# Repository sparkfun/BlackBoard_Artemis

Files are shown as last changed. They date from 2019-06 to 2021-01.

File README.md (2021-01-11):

**NOTE:** *This product has been retired from our catalog. There is an updated RedBoard version available: [DEV-15444](https://www.sparkfun.com/products/15444). If you are looking for more up-to-date info, please check out some of these resources to see how other users are still hacking and improving on this product version.*

* *[SparkFun Artemis Forum](https://forum.sparkfun.com/viewforum.php?f=167)*
* *[Comments Here on GitHub](https://github.com/sparkfun/BlackBoard_Artemis/issues)*

SparkFun BlackBoard Artemis
============================

[SparkFun BlackBoard Artemis  
*SparkFun BlackBoard (SPX-15332)*](https://www.sparkfun.com/products/15332)

Think of the BlackBoard Artemis as just another Arduino... That has BLE. And one meg of flash. And runs at less than 1mA. Oh, and it can run TensorFlow models. Ya, that too. The BlackBoard Artemis takes the incredibly powerful Artemis module from SparkFun and wraps it up in an easy to use and familiar Uno footprint. We've written an Arduino core from scratch to make programming the Artemis as familiar as `Serial.begin(9600)`. Time-to-first-blink is less than five minutes.

The BlackBoard Artemis has the improved power conditioning and USB to serial that we've refined over the years on our BlackBoard line of products. A modern USB-C connector makes programming easy. A Qwiic connector makes I<sup>2</sup>C easy. The BlackBoard Artemis is fully compatible with SparkFun's Arduino core and can be programmed easily under the Arduino IDE. We've exposed the JTAG connector for more advanced users who prefer to use the power and speed of professional tools. We've added a digital MEMS microphone for folks wanting to experiment with always-on voice commands with TensorFlow and machine learning. We've even added a convenient jumper to measure current consumption for low power testing.

With 1M flash and 384k RAM you'll have plenty of room for your sketches. The Artemis module runs at 48MHz with a 96MHz turbo mode available and with Bluetooth to boot!

The SparkFun BlackBoard Artemis is a great platform to 'kick the tires' of this amazing module. If you're interesting in testing out the full capabilities of the SparkFun Artemis module or if you're looking for more compact solution, be sure to checkout our ATP and Nano versions of the Artemis line.

**Note:** We are actively working on getting FCC and compliance certifications for the SparkFun Artemis Module. Once our certifications are complete we will be moving the BlackBoard to a RedBoard format with the FCC Certified version of the Artemis on board. *Please be aware* that this could happen as soon as a few weeks to a month so this BlackBoard version is for those of you who can't wait and want to start using the SparkFun Artemis as soon as possible!

Repository Contents
-------------------
* **/Hardware** - Eagle design files (.brd, .sch)

Documentation
-------------------
* **[Hookup Guide for the BlackBoard Artemis](https://learn.sparkfun.com/tutorials/hookup-guide-for-the-blackboard-artemis)**
* **[Designing with the SparkFun Artemis](https://learn.sparkfun.com/tutorials/designing-with-the-sparkfun-artemis)** - Layout and design considerations when using the Artemis module.
* **[Artemis Development with Arduino](https://learn.sparkfun.com/tutorials/artemis-development-with-arduino)** - Introduction to the Arduino core for the Artemis Module.
* **[Ambiq Apollo3 SDK SetUp](https://learn.sparkfun.com/tutorials/using-sparkfun-edge-board-with-ambiq-apollo3-sdk)** - Getting set up with the Apollo3 Software Development Kit.
* **[CH340E USB to serial IC Drivers](https://www.sparkfun.com/ch340)**
* **[SparkFun Fritzing repo](https://github.com/sparkfun/Fritzing_Parts)** - Fritzing diagrams for SparkFun products.
License Information
-------------------

This product is _**open source**_! 

Please review the LICENSE.md file for license information. 

If you have any questions or concerns on licensing, please contact techsupport@sparkfun.com.

Please use, reuse, and modify these files as you see fit. Please maintain attribution to SparkFun Electronics and release any derivative under the same license.

Distributed as-is; no warranty is given.

- Your friends at SparkFun.

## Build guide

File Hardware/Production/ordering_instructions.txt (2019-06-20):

panel size, 160x121mm
PCB thickness, 1.6mm
number of layers, 2
soldermask color, Red
silkscreen color, White
oz copper, 1oz
finish, HASL lead free
stencils, top+bottom
pcs per panel, 4
min trace width, 0.177800mm / 0.007000in
min drill size, 0.304800mm / 0.012000in

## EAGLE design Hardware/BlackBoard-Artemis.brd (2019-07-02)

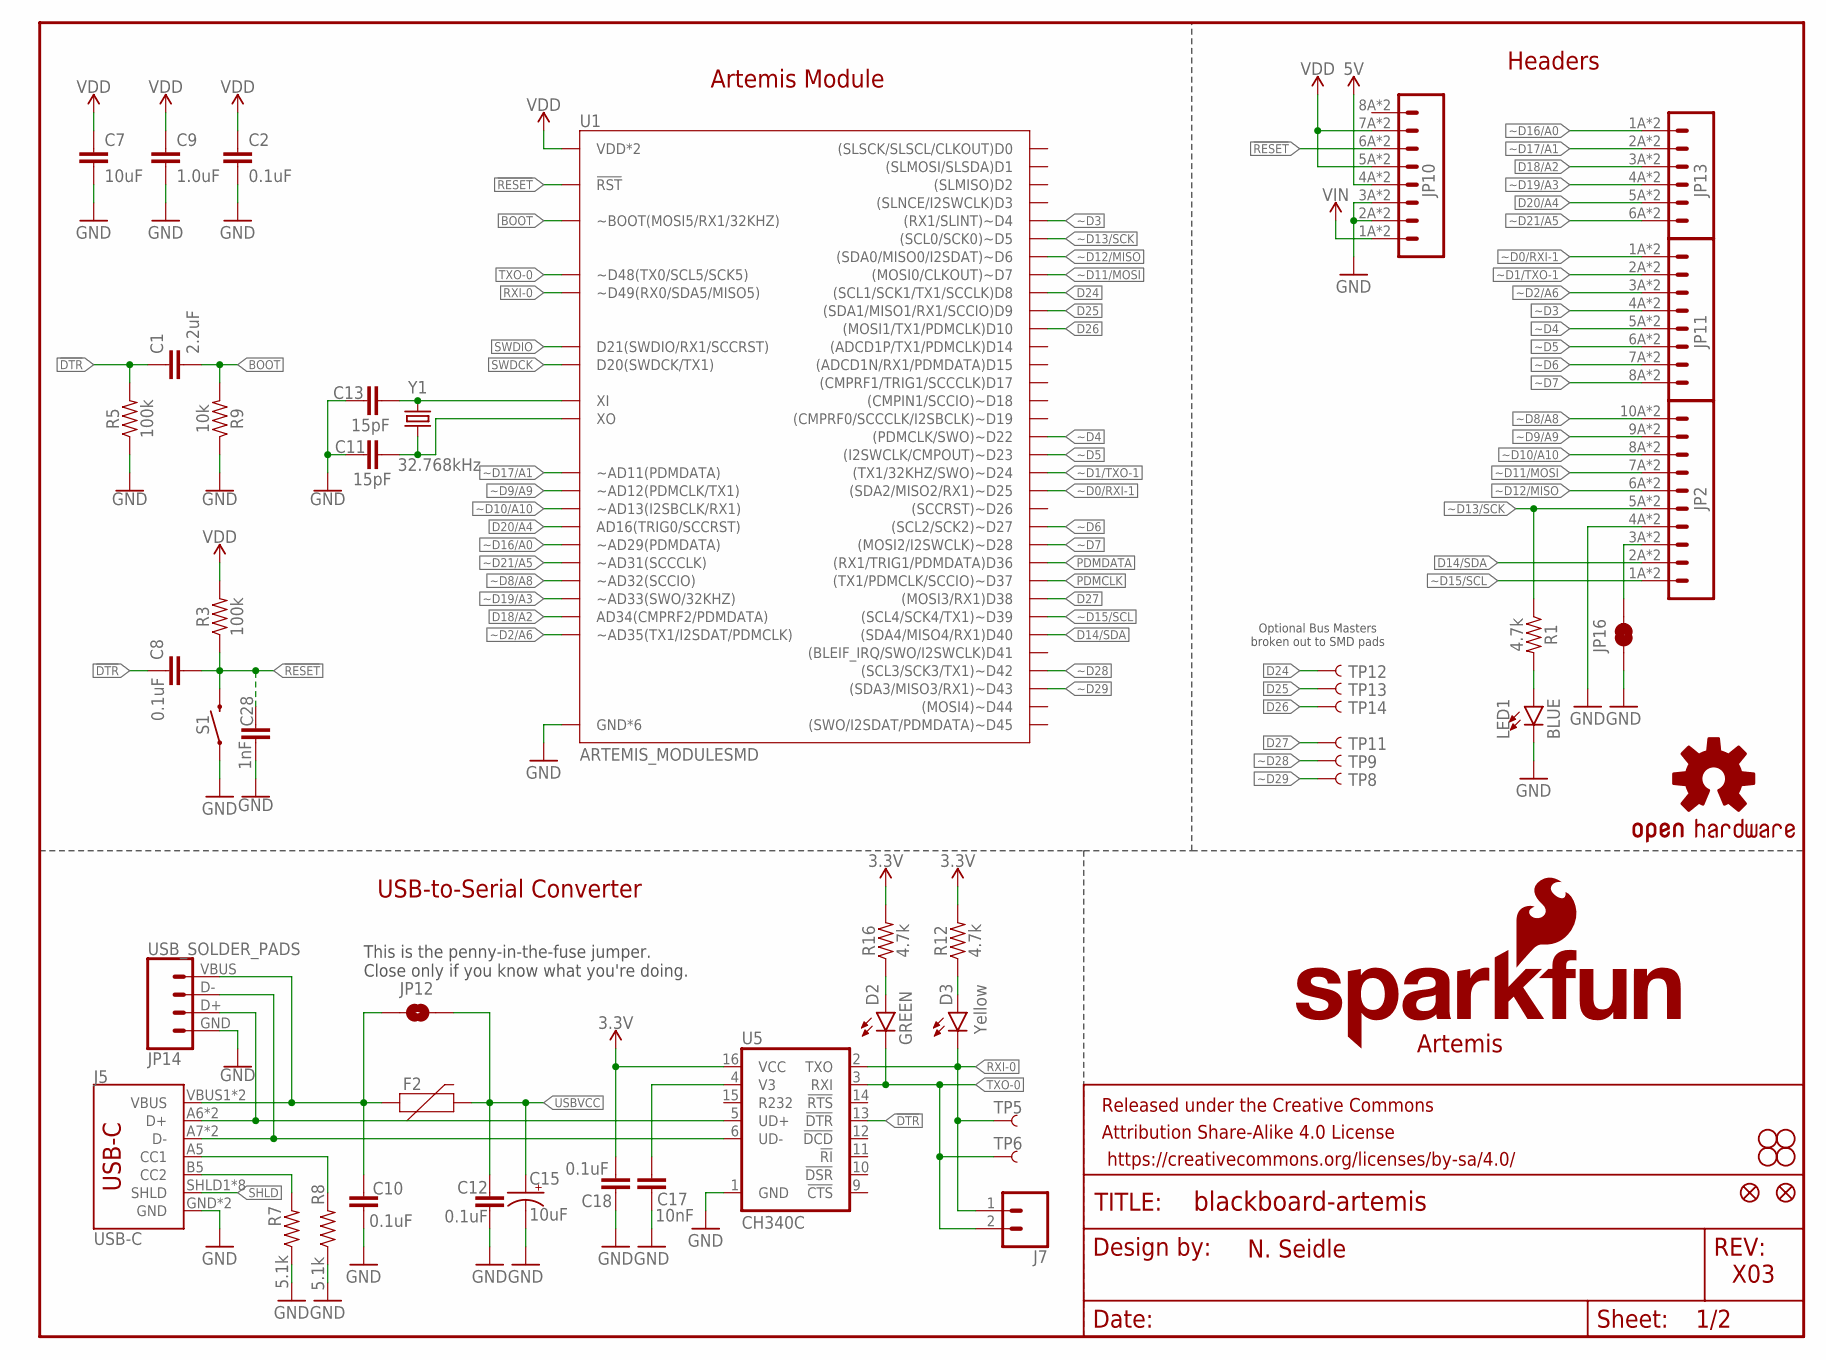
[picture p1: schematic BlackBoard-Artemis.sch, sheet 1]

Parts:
C1: 2.2uF; 0603
C2, C8, C10, C12, C18: 0.1uF; 0603
C7: 10uF; 0603
C9: 1.0uF; 0603
C11, C13: 15pF; 0603
C15: 10uF; EIA3216
C17: 10nF; 0603
C28: 1nF; 0603
D2: GREEN; LED-1206
D3: Yellow; LED-1206
F2: 6V/2A; 1210
FRAME1: FRAME-LETTER; CREATIVE_COMMONS
J5: USB-C; USB-C-16P
J7: CONN_021X02_NO_SILK; 1X02_NO_SILK
JP1: SFE_LOGO_NAME.1_INCH; SFE_LOGO_NAME_.1
JP2: M10SMD_COMBO; 1X10_SMD_COMBINED
JP3, JP4, JP5, JP6: STAND-OFF
JP7: SFE_LOGO_FLAME.1_INCH; SFE_LOGO_FLAME_.1
JP8, JP9: FIDUCIAL1X2; FIDUCIAL-1X2
JP10: M08SMD-COMBO; 1X08_SMD_COMBINED
JP11: JP11; 1X08_SMD_COMBINED
JP12: JUMPER-SMT_2_NO_SILK; SMT-JUMPER_2_NO_SILK
JP13: M06SMD-STRAIGHT-COMBO; 1X06_SMD_STRAIGHT_COMBO
JP14: USB_SOLDER_PADS; USB-SOLDER-PADS
JP16: JUMPER-SMT_2_NC_TRACE_SILK; SMT-JUMPER_2_NC_TRACE_SILK
LED1: BLUE; LED-1206
R1, R12, R16: 4.7k; 0603
R3, R5: 100k; 0603
R7, R8: 5.1k; 0603
R9: 10k; 0603
S1: MOMENTARY-SWITCH-SPST-SMD-5.2-TALL-REDUNDANT; TACTILE_SWITCH_SMD_5.2MM
TP5, TP6, TP8, TP9, TP11, TP12, TP13, TP14: TEST-POINT3X5; PAD.03X.05
U1: ARTEMIS_MODULESMD; ARTEMIS_FP
U5: CH340C; SO016
U$16: OSHW-LOGOS; OSHW-LOGO-S
Y1: 32.768kHz; CRYSTAL-SMD-3.2X1.5MM

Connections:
3.3V: C18.1, R12.2, R16.2, U5.16 (VCC); also elsewhere on the board
5V: JP10.4A (4), JP10.4B (4); also elsewhere on the board
!DTR: C1.1, C8.1, R5.2, U5.13 (!DTR)
!RESET: C8.2, C28.1, JP10.6A (6), JP10.6B (6), R3.1, S1.3 (2), S1.4 (2), U1.~RST (!RST); also elsewhere on the board
BOOT: C1.2, R9.2, U1.BOOT (~BOOT(MOSI5/RX1/32KHZ))
CC1: J5.A5 (CC1), R8.2
CC2: J5.B5 (CC2), R7.2
D14/SDA: JP2.2A (2), JP2.2B (2), U1.D40 ((SDA4/MISO4/RX1)D40); also elsewhere on the board
D18/A2: JP13.3A (3), JP13.3B (3), U1.AD34 (AD34(CMPRF2/PDMDATA))
D20/A4: JP13.5A (5), JP13.5B (5), U1.AD16 (AD16(TRIG0/SCCRST))
D24: TP12.P$1, U1.D8 ((SCL1/SCK1/TX1/SCCLK)D8)
D25: TP13.P$1, U1.D9 ((SDA1/MISO1/RX1/SCCIO)D9)
D26: TP14.P$1, U1.D10 ((MOSI1/TX1/PDMCLK)D10)
D27: TP11.P$1, U1.D38 ((MOSI3/RX1)D38)
D+: J5.A6 (D+), J5.B6 (D+), JP14.D+ (3), U5.5 (UD+)
D-: J5.A7 (D-), J5.B7 (D-), JP14.D- (2), U5.6 (UD-)
GND: C2.1, C7.2, C9.2, C10.2, C11.1, C12.2, C13.1, C15.-, C17.2, C18.2, C28.2, J5.GND, J5.GND2 (GND), JP2.4A (4), JP2.4B (4), JP10.2A (2), JP10.2B (2), JP10.3A (3), JP10.3B (3), JP14.GND (4), JP16.1, LED1.C, R5.1, R7.1, R8.1, R9.1, S1.1, S1.2 (1), U1.GND@1 (GND*6), U1.GND@22 (GND*6), U1.GND@38 (GND*6), U1.GND@39 (GND*6), U1.GND@47 (GND*6), U1.GND@59 (GND*6), U5.1 (GND); also elsewhere on the board
unnamed: LED1.A, R1.2
unnamed: D2.A, R16.1
unnamed: C17.1, U5.4 (V3)
unnamed: C11.2, U1.XO, Y1.P$2 (2)
unnamed: C13.2, U1.XI, Y1.P$1 (1)
unnamed: D3.A, R12.1
unnamed: JP2.3A (3), JP2.3B (3), JP16.2
PDMCLK: U1.~D37 ((TX1/PDMCLK/SCCIO)~D37); also elsewhere on the board
PDMDATA: U1.D36 ((RX1/TRIG1/PDMDATA)D36); also elsewhere on the board
RXI-0: D3.C, J7.1, TP5.P$1, U1.RXI-0 (~D49(RX0/SDA5/MISO5)), U5.2 (TXO)
SHLD: J5.SHLD1 (SHLD), J5.SHLD2 (SHLD), J5.SHLD3 (SHLD), J5.SHLD4 (SHLD), J5.SHLD5 (SHLD), J5.SHLD6 (SHLD), J5.SHLD7 (SHLD), J5.SHLD8 (SHLD)
SWDCK: U1.SWDCK (D20(SWDCK/TX1)); also elsewhere on the board
SWDIO: U1.SWDIO (D21(SWDIO/RX1/SCCRST)); also elsewhere on the board
TXO-0: D2.C, J7.2, TP6.P$1, U1.TXO-0 (~D48(TX0/SCL5/SCK5)), U5.3 (RXI)
USBVCC: C12.1, C15.+, F2.2, JP12.2; also elsewhere on the board
VDD: C2.2, C7.1, C9.1, JP10.5A (5), JP10.5B (5), JP10.7A (7), JP10.7B (7), R3.2, U1.VDD@36 (VDD*2), U1.VDD@37 (VDD*2); also elsewhere on the board
VIN: JP10.1A (1), JP10.1B (1); also elsewhere on the board
VUSB: C10.1, F2.1, J5.VBUS1 (VBUS), J5.VBUS2 (VBUS), JP12.1, JP14.VBUS (1)
~D0/RXI-1: JP11.1A (1), JP11.1B (1), U1.~D25 ((SDA2/MISO2/RX1)~D25)
~D1/TXO-1: JP11.2A (2), JP11.2B (2), U1.~D24 ((TX1/32KHZ/SWO)~D24)
~D2/A6: JP11.3A (3), JP11.3B (3), U1.~AD35 (~AD35(TX1/I2SDAT/PDMCLK))
~D3: JP11.4A (4), JP11.4B (4), U1.~D4 ((RX1/SLINT)~D4)
~D4: JP11.5A (5), JP11.5B (5), U1.~D22 ((PDMCLK/SWO)~D22)
~D5: JP11.6A (6), JP11.6B (6), U1.~D23 ((I2SWCLK/CMPOUT)~D23)
~D6: JP11.7A (7), JP11.7B (7), U1.~D27 ((SCL2/SCK2)~D27)
~D7: JP11.8A (8), JP11.8B (8), U1.~D28 ((MOSI2/I2SWCLK)~D28)
~D8/A8: JP2.10A (10), JP2.10B (10), U1.~AD32 (~AD32(SCCIO))
~D9/A9: JP2.9A (9), JP2.9B (9), U1.~AD12 (~AD12(PDMCLK/TX1))
~D10/A10: JP2.8A (8), JP2.8B (8), U1.~AD13 (~AD13(I2SBCLK/RX1))
~D11/MOSI: JP2.7A (7), JP2.7B (7), U1.D7 ((MOSI0/CLKOUT)~D7)
~D12/MISO: JP2.6A (6), JP2.6B (6), U1.~D6 ((SDA0/MISO0/I2SDAT)~D6)
~D13/SCK: JP2.5A (5), JP2.5B (5), R1.1, U1.~D5 ((SCL0/SCK0)~D5)
~D15/SCL: JP2.1A (1), JP2.1B (1), U1.~D39 ((SCL4/SCK4/TX1)~D39); also elsewhere on the board
~D16/A0: JP13.1A (1), JP13.1B (1), U1.~AD29 (~AD29(PDMDATA))
~D17/A1: JP13.2A (2), JP13.2B (2), U1.~AD11 (~AD11(PDMDATA))
~D19/A3: JP13.4A (4), JP13.4B (4), U1.~AD33/SWO (~AD33(SWO/32KHZ)); also elsewhere on the board
~D21/A5: JP13.6A (6), JP13.6B (6), U1.~AD31 (~AD31(SCCCLK))
~D28: TP9.P$1, U1.~D42 ((SCL3/SCK3/TX1)~D42)
~D29: TP8.P$1, U1.~D43 ((SDA3/MISO3/RX1)~D43)

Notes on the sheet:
Artemis
USB-to-Serial Converter
N. Seidle
X03
This is the penny-in-the-fuse jumper. Close only if you know what you're doing.
Optional Bus Masters broken out to SMD pads
Artemis Module
Headers

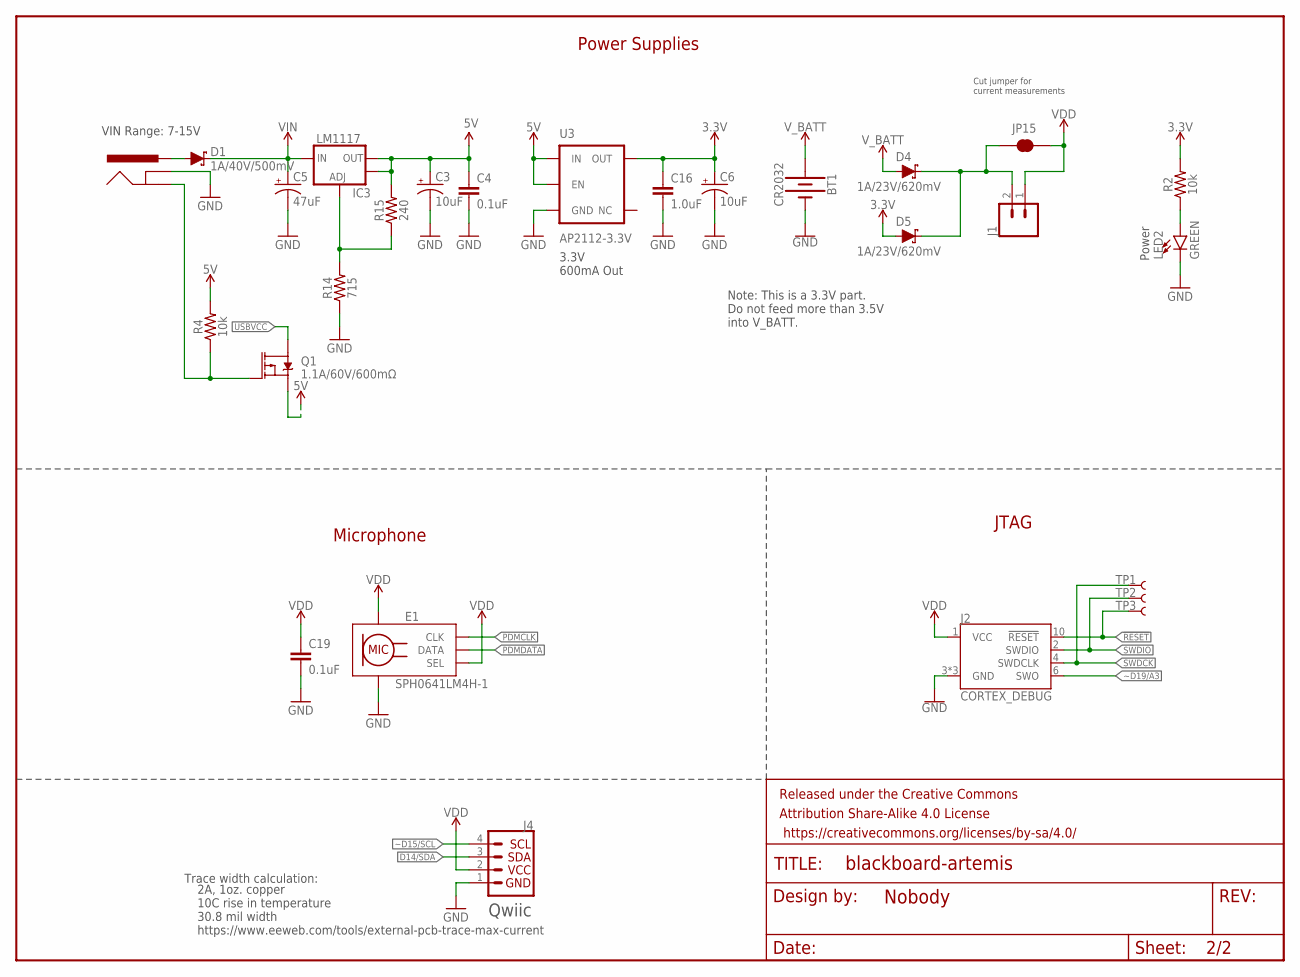
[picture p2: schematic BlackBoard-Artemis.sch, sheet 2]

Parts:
BT1: CR2032; BATTCON_20MM_4LEGS_OVERPASTE
C3, C6: 10uF; EIA3216
C4, C19: 0.1uF; 0603
C5: 47uF; PANASONIC_D
C16: 1.0uF; 0603
D1: 1A/40V/500mV; SMA-DIODE
D4, D5: 1A/23V/620mV; SOD-323
E1: SPH0641LM4H-1; SPH0641LM4H-1_MICROPHONE
FRAME2: FRAME-LETTERNO_PACKAGE; DUMMY
IC3: LM1117; SOT223-ALT1
J1: CONN_021X02_NO_SILK; 1X02_NO_SILK
J2: CORTEX_DEBUG; 2X5-PTH-1.27MM-NO_SILK
J3: POWER_JACKTOE; POWER_JACK_SMD_OVERPASTE_TOE
J4: QWIIC_CONNECTORJS-1MM; JST04_1MM_RA
JP15: JUMPER-SMT_2_NC_TRACE_SILK; SMT-JUMPER_2_NC_TRACE_SILK
LED2: GREEN; LED-1206
Q1: 1.1A/60V/600mΩ; SOT23-3
R2, R4: 10k; 0603
R14: 715; 0603
R15: 240; 0603
TP1, TP2, TP3: TEST-POINT3X5; PAD.03X.05
U3: AP2112-3.3V; SOT23-5

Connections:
3.3V: C6.+, C16.1, D5.A, R2.2, U3.5 (OUT); also elsewhere on the board
5V: C3.+, C4.1, IC3.2 (OUT), IC3.4 (OUT), Q1.2 (S), R4.2, R15.2, U3.1 (IN), U3.3 (EN); also elsewhere on the board
!RESET: J2.10 (!RESET), TP3.P$1; also elsewhere on the board
D14/SDA: J4.3; also elsewhere on the board
GND: BT1.2 (-), C3.-, C4.2, C5.-, C6.-, C16.2, C19.2, E1.3 (GND), E1.6 (GND), E1.7 (GND), E1.8 (GND), J2.3 (GND), J2.5 (GND), J2.9 (GND), J3.GND (GNDBREAK), J4.1, LED2.C, R14.1, U3.2 (GND); also elsewhere on the board
INSERT: J3.P$4 (GND), Q1.1 (G), R4.1
unnamed: LED2.A, R2.1
unnamed: D4.C, D5.C, J1.2, JP15.1
unnamed: IC3.1 (ADJ), R14.2, R15.1
PDMCLK: E1.4 (CLK); also elsewhere on the board
PDMDATA: E1.1 (DATA); also elsewhere on the board
PWRIN: D1.A, J3.VIN0 (PWR)
SWDCK: J2.4 (SWDCLK), TP1.P$1; also elsewhere on the board
SWDIO: J2.2 (SWDIO), TP2.P$1; also elsewhere on the board
USBVCC: Q1.3 (D); also elsewhere on the board
VDD: C19.1, E1.2 (SEL), E1.5 (VDD), J1.1, J2.1 (VCC), J4.2, JP15.2; also elsewhere on the board
VIN: C5.+, D1.C, IC3.3 (IN); also elsewhere on the board
V_BATT: BT1.1 (+), D4.A
~D15/SCL: J4.4; also elsewhere on the board
~D19/A3: J2.6 (SWO); also elsewhere on the board

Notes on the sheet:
VIN Range: 7-15V
3.3V 600mA Out
Cut jumper for current measurements
Power Supplies
Microphone
Note: This is a 3.3V part. Do not feed more than 3.5V into V_BATT.
Qwiic
Trace width calculation:
2A, 1oz. copper 10C rise in temperature 30.8 mil width https://www.eeweb.com/tools/external-pcb-trace-max-current
JTAG
Power

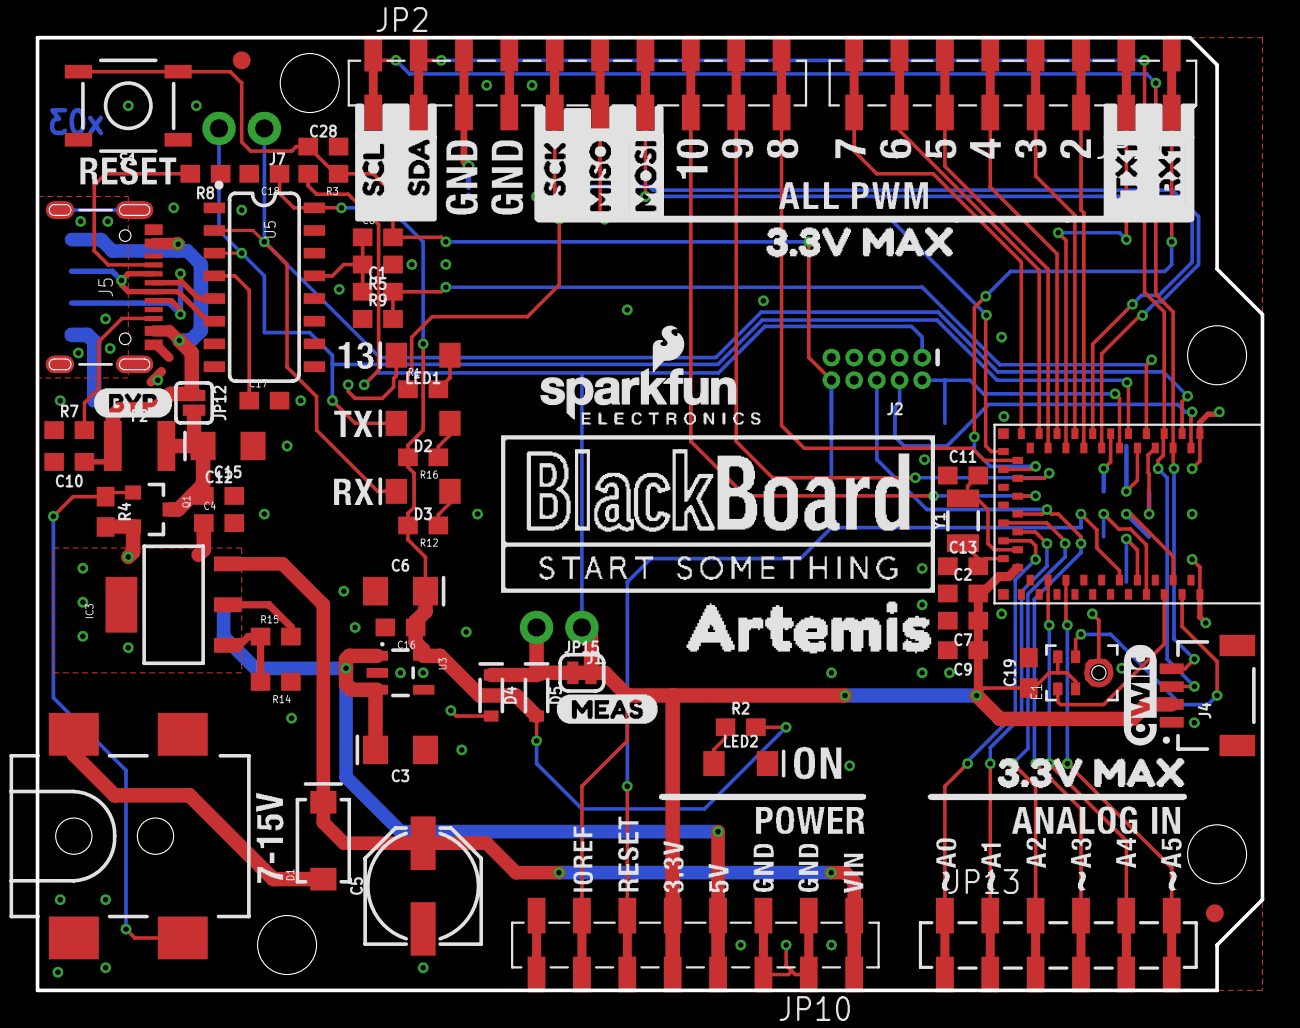
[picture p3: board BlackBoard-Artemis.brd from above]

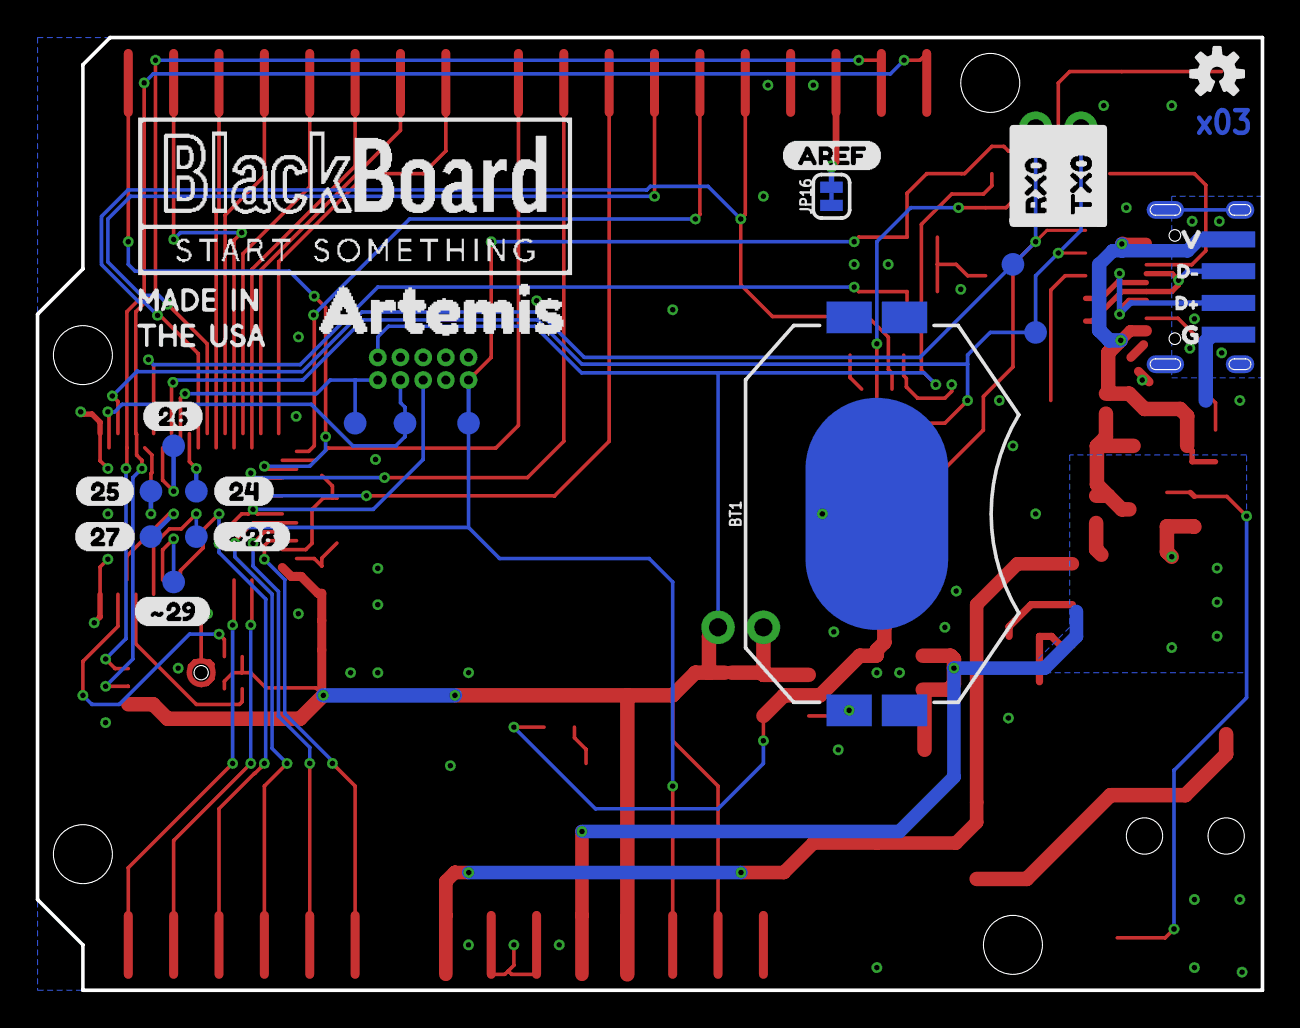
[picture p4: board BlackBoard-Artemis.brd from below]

Board: 2 copper layers, 68.6 x 53.3 mm, 114 parts (32 on the bottom side), 62 nets.

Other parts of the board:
U$1, U$3: BLACKBOARDLOGO#PNG
U$2: D#3
U$4: MADEINUSA#PNG
U$9: QWIIC_COPYRIGHT_SMALL
U$10: D#4
U$11: G1
U$12: V0
U$13, U$67: 3#3V_MAX2
U$14, U$15: ARTEMIS0
U$17: #284
U$18: SCL1
U$19: #295
U$20: AREF2
U$21: 240
U$22: SDA0
U$23: 251
U$24: 262
U$25: 273
U$47: MISO8
U$48: MOSI7
U$49: RX01
U$50: SCK9
U$53: TX00
U$68: BYP0
U$70: MEAS3
U$71: RX11
U$72: TX10

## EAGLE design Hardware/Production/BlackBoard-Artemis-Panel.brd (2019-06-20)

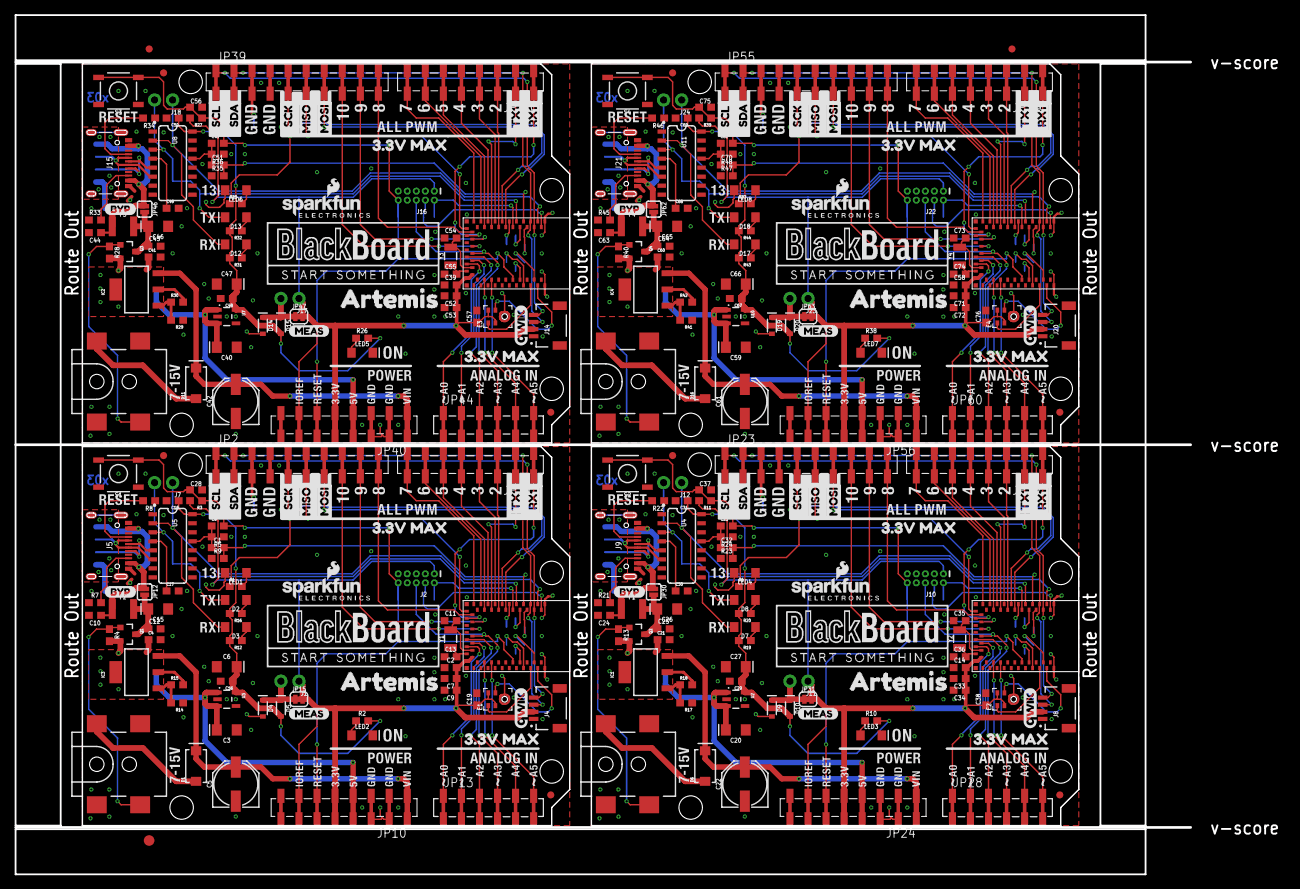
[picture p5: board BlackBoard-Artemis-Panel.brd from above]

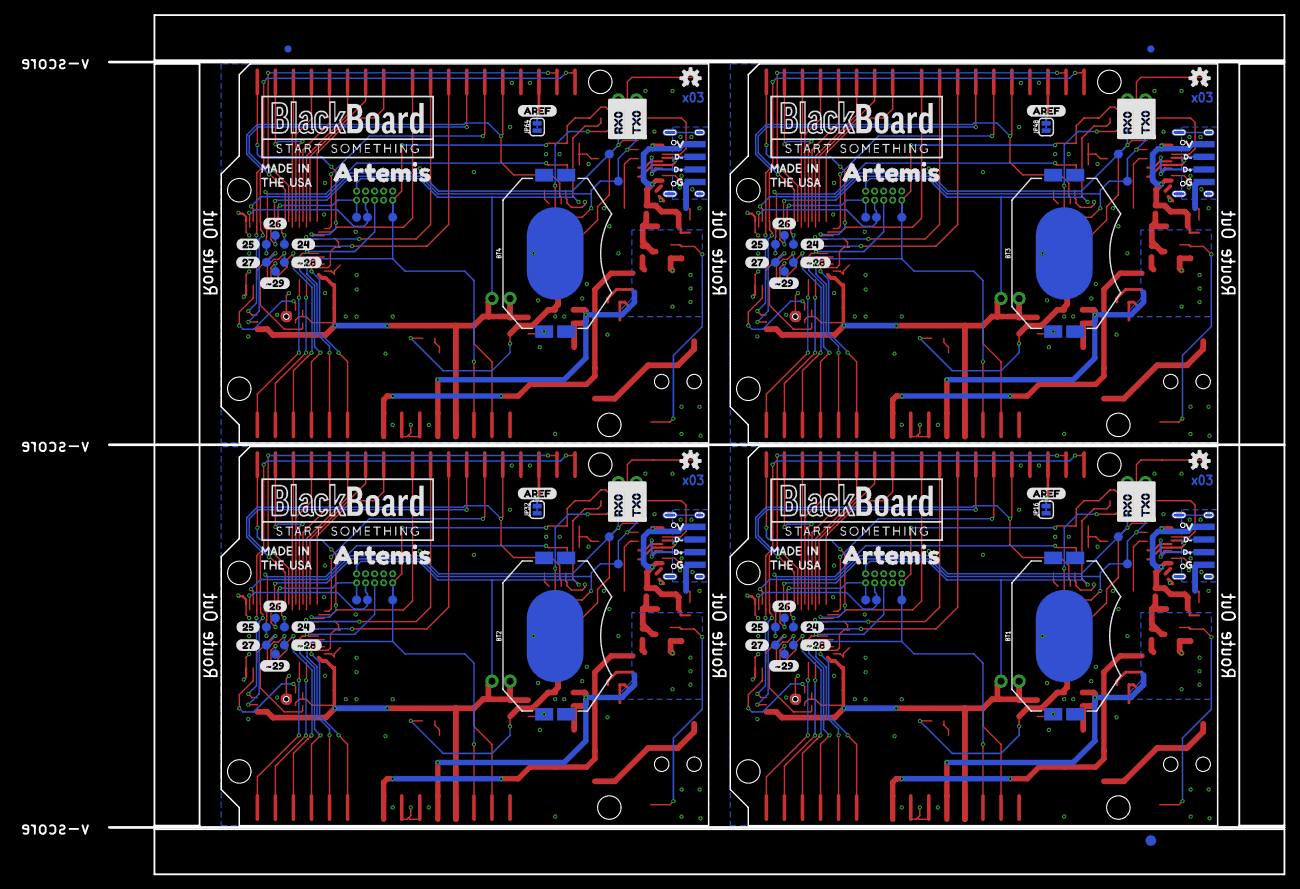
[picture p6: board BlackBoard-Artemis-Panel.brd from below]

Board: 2 copper layers, 165.4 x 120.9 mm, 458 parts (131 on the bottom side), 248 nets.

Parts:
BT1, BT2, BT3, BT4: CR2032; BATTCON_20MM_4LEGS_OVERPASTE
C1, C32, C51, C70: 2.2uF; 0603
C2, C4, C8, C10, C12, C14, C18, C19, C21, C23, C24, C25, C31, C38, C39, C41, C43, C44, C45, C50, C57, C58, C60, C62, C63, C64, C69, C76: 0.1uF; 0603
C3, C6, C15, C20, C26, C27, C40, C46, C47, C59, C65, C66: 10uF; EIA3216
C5, C22, C42, C61: 47uF; PANASONIC_D
C7, C33, C52, C71: 10uF; 0603
C9, C16, C29, C34, C48, C53, C67, C72: 1.0uF; 0603
C11, C13, C35, C36, C54, C55, C73, C74: 15pF; 0603
C17, C30, C49, C68: 10nF; 0603
C28, C37, C56, C75: 1nF; 0603
D1, D6, D11, D16: 1A/40V/500mV; SMA-DIODE
D2, D8, D13, D18: GREEN; LED-1206
D3, D7, D12, D17: Yellow; LED-1206
D4, D5, D9, D10, D14, D15, D19, D20: 1A/23V/620mV; SOD-323
E1, E2, E3, E4: SPH0641LM4H-1; SPH0641LM4H-1_MICROPHONE
E$1, E$2, E$3, E$4: FIDUCIAL-1X2
E$5, E$6: FIDUCIAL-1.5X3
F1, F2, F3, F4: 6V/2A; 1210
FRAME1, FRAME2, FRAME3, FRAME4: FRAME-LETTERNO_PACKAGE; DUMMY
IC1, IC2, IC3, IC4: LM1117; SOT223-ALT1
J1, J7, J11, J12, J17, J18, J23, J24: 1X02_NO_SILK
J2, J10, J16, J22: CORTEX_DEBUG; 2X5-PTH-1.27MM-NO_SILK
J3, J6, J13, J19: POWER_JACKTOE; POWER_JACK_SMD_OVERPASTE_TOE
J4, J8, J14, J20: JST04_1MM_RA
J5, J9, J15, J21: USB-C; USB-C-16P
JP1, JP25, JP41, JP57: SFE_LOGO_NAME.1_INCH; SFE_LOGO_NAME_.1
JP2, JP23, JP39, JP55: M10SMD_COMBO; 1X10_SMD_COMBINED
JP3, JP4, JP5, JP6, JP17, JP18, JP19, JP20, JP33, JP34, JP35, JP36, JP49, JP50, JP51, JP52: STAND-OFF
JP7, JP26, JP42, JP58: SFE_LOGO_FLAME.1_INCH; SFE_LOGO_FLAME_.1
JP8, JP9, JP21, JP22, JP37, JP38, JP53, JP54: FIDUCIAL1X2; FIDUCIAL-1X2
JP10, JP24, JP40, JP56: 1X08_SMD_COMBINED
JP11, JP27, JP43, JP59: JP11; 1X08_SMD_COMBINED
JP12, JP30, JP46, JP62: SMT-JUMPER_2_NO_SILK
JP13, JP28, JP44, JP60: 1X06_SMD_STRAIGHT_COMBO
JP14, JP29, JP45, JP61: USB_SOLDER_PADS; USB-SOLDER-PADS
JP15, JP16, JP31, JP32, JP47, JP48, JP63, JP64: SMT-JUMPER_2_NC_TRACE_SILK
LED1, LED4, LED6, LED8: BLUE; LED-1206
LED2, LED3, LED5, LED7: GREEN; LED-1206
Q1, Q2, Q3, Q4: 1.1A/60V/600mΩ; SOT23-3
R1, R6, R12, R16, R19, R20, R25, R31, R32, R37, R43, R44: 4.7k; 0603
R2, R4, R9, R10, R13, R23, R26, R28, R35, R38, R40, R47: 10k; 0603
R3, R5, R11, R24, R27, R36, R39, R48: 100k; 0603
R7, R8, R21, R22, R33, R34, R45, R46: 5.1k; 0603
R14, R17, R29, R41: 715; 0603
R15, R18, R30, R42: 240; 0603
S1, S2, S3, S4: TACTILE_SWITCH_SMD_5.2MM
TP1, TP2, TP3, TP4, TP7, TP8, TP9, TP11, TP12, TP13, TP14, TP16, TP17, TP18, TP19, TP20, TP21, TP22, TP23, TP24, TP27, TP28, TP29, TP30, TP31, TP32, TP33, TP34, TP35, TP38, TP39, TP40, TP41, TP42, TP43, TP44: PAD.03X.05
TP5, TP6, TP10, TP15, TP25, TP26, TP36, TP37: TEST-POINT3X5; PAD.03X.05
U1, U6, U9, U12: ARTEMIS_MODULESMD; ARTEMIS_FP
U2, U3, U7, U10: AP2112-3.3V; SOT23-5
U4, U5, U8, U11: CH340C; SO016
U$1, U$3, U$6, U$7, U$59, U$60, U$95, U$96: BLACKBOARDLOGO#PNG
U$2, U$29, U$65, U$101: D#3
U$4, U$8, U$61, U$97: MADEINUSA#PNG
U$5, U$16, U$58, U$94: OSHW-LOGOS; OSHW-LOGO-S
U$9, U$26, U$62, U$98: QWIIC_COPYRIGHT_SMALL
U$10, U$30, U$66, U$102: D#4
U$11, U$27, U$63, U$99: G1
U$12, U$28, U$64, U$100: V0
U$13, U$36, U$46, U$67, U$77, U$87, U$108, U$118: 3#3V_MAX2
U$14, U$15, U$31, U$32, U$69, U$73, U$103, U$104: ARTEMIS0
U$17, U$51, U$88, U$119: #284
U$18, U$43, U$84, U$115: SCL1
U$19, U$52, U$89, U$120: #295
U$20, U$42, U$83, U$114: AREF2
U$21, U$54, U$90, U$121: 240
U$22, U$44, U$85, U$116: SDA0
U$23, U$55, U$91, U$122: 251
U$24, U$56, U$92, U$123: 262
U$25, U$57, U$93, U$124: 273
U$33, U$47, U$74, U$105: MISO8
U$34, U$48, U$75, U$106: MOSI7
U$35, U$50, U$76, U$107: SCK9
U$37, U$70, U$78, U$109: MEAS3
U$38, U$71, U$79, U$110: RX11
U$39, U$72, U$80, U$111: TX10
U$40, U$49, U$81, U$112: RX01
U$41, U$53, U$82, U$113: TX00
U$45, U$68, U$86, U$117: BYP0
Y1, Y2, Y3, Y4: 32.768kHz; CRYSTAL-SMD-3.2X1.5MM

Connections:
3.3V: C6.+, C16.1, C18.1, D5.A, R2.2, R12.2, R16.2, U3.5, U5.16
3.3V1: C27.+, C29.1, C31.1, D10.A, R10.2, R19.2, R20.2, U2.5, U4.16
3.3V2: C47.+, C48.1, C50.1, D15.A, R26.2, R31.2, R32.2, U7.5, U8.16
3.3V3: C66.+, C67.1, C69.1, D20.A, R38.2, R43.2, R44.2, U10.5, U11.16
5V: C3.+, C4.1, IC3.2, IC3.4, JP10.4A, JP10.4B, Q1.2, R4.2, R15.2, U3.1, U3.3
5V1: C20.+, C21.1, IC1.2, IC1.4, JP24.4A, JP24.4B, Q2.2, R13.2, R18.2, U2.1, U2.3
5V2: C40.+, C41.1, IC2.2, IC2.4, JP40.4A, JP40.4B, Q3.2, R28.2, R30.2, U7.1, U7.3
5V3: C59.+, C60.1, IC4.2, IC4.4, JP56.4A, JP56.4B, Q4.2, R40.2, R42.2, U10.1, U10.3
!DTR: C1.1, C8.1, R5.2, U5.13
!DTR1: C23.1, C32.1, R24.2, U4.13
!DTR2: C43.1, C51.1, R36.2, U8.13
!DTR3: C62.1, C70.1, R48.2, U11.13
!RESET: C8.2, C28.1, J2.10, JP10.6A, JP10.6B, R3.1, S1.3, S1.4, TP3.P$1, U1.~RST
!RESET1: C23.2, C37.1, J10.10, JP24.6A, JP24.6B, R11.1, S2.3, S2.4, TP16.P$1, U6.~RST
!RESET2: C43.2, C56.1, J16.10, JP40.6A, JP40.6B, R27.1, S3.3, S3.4, TP27.P$1, U9.~RST
!RESET3: C62.2, C75.1, J22.10, JP56.6A, JP56.6B, R39.1, S4.3, S4.4, TP38.P$1, U12.~RST
BOOT: C1.2, R9.2, U1.BOOT
BOOT1: C32.2, R23.2, U6.BOOT
BOOT2: C51.2, R35.2, U9.BOOT
BOOT3: C70.2, R47.2, U12.BOOT
CC1: J5.A5, R8.2
CC2: J5.B5, R7.2
CC3: J9.B5, R21.2
CC4: J9.A5, R22.2
CC5: J15.B5, R33.2
CC6: J15.A5, R34.2
CC7: J21.B5, R45.2
CC8: J21.A5, R46.2
D1: TP20.P$1, U6.D8
D2: TP21.P$1, U6.D9
D3: TP22.P$1, U6.D10
D4: TP19.P$1, U6.D38
D5: TP31.P$1, U9.D8
D6: TP32.P$1, U9.D9
D7: TP33.P$1, U9.D10
D8: TP30.P$1, U9.D38
D9: TP42.P$1, U12.D8
D10: TP43.P$1, U12.D9
D11: TP44.P$1, U12.D10
D12: TP41.P$1, U12.D38
D14/SDA: J4.3, JP2.2A, JP2.2B, U1.D40
D14/SDA1: J8.3, JP23.2A, JP23.2B, U6.D40
D14/SDA2: J14.3, JP39.2A, JP39.2B, U9.D40
D14/SDA3: J20.3, JP55.2A, JP55.2B, U12.D40
D18/A1: JP28.3A, JP28.3B, U6.AD34
D18/A2: JP13.3A, JP13.3B, U1.AD34
D18/A3: JP44.3A, JP44.3B, U9.AD34
D18/A4: JP60.3A, JP60.3B, U12.AD34
D20/A1: JP28.5A, JP28.5B, U6.AD16
D20/A2: JP44.5A, JP44.5B, U9.AD16
D20/A3: JP60.5A, JP60.5B, U12.AD16
D20/A4: JP13.5A, JP13.5B, U1.AD16
D24: TP12.P$1, U1.D8
D25: TP13.P$1, U1.D9
D26: TP14.P$1, U1.D10
D27: TP11.P$1, U1.D38
D+: J5.A6, J5.B6, JP14.D+, U5.5
D+1: J9.A6, J9.B6, JP29.D+, U4.5
D+2: J15.A6, J15.B6, JP45.D+, U8.5
D+3: J21.A6, J21.B6, JP61.D+, U11.5
D-: J5.A7, J5.B7, JP14.D-, U5.6
D-1: J9.A7, J9.B7, JP29.D-, U4.6
D-2: J15.A7, J15.B7, JP45.D-, U8.6
D-3: J21.A7, J21.B7, JP61.D-, U11.6
GND: BT1.2, C2.1, C3.-, C4.2, C5.-, C6.-, C7.2, C9.2, C10.2, C11.1, C12.2, C13.1, C15.-, C16.2, C17.2, C18.2, C19.2, C28.2, E1.3, E1.6, E1.7, E1.8, J2.3, J2.5, J2.9, J3.GND, J4.1, J5.GND, J5.GND2, JP2.4A, JP2.4B, JP10.2A, JP10.2B, JP10.3A, JP10.3B, JP14.GND, JP16.1, LED1.C, LED2.C, R5.1, R7.1, R8.1, R9.1, R14.1, S1.1, S1.2, U1.GND@1, U1.GND@22, U1.GND@38, U1.GND@39, U1.GND@47, U1.GND@59, U3.2, U5.1
GND1: BT2.2, C14.1, C20.-, C21.2, C22.-, C24.2, C25.2, C26.-, C27.-, C29.2, C30.2, C31.2, C33.2, C34.2, C35.1, C36.1, C37.2, C38.2, E2.3, E2.6, E2.7, E2.8, J6.GND, J8.1, J9.GND, J9.GND2, J10.3, J10.5, J10.9, JP23.4A, JP23.4B, JP24.2A, JP24.2B, JP24.3A, JP24.3B, JP29.GND, JP32.1, LED3.C, LED4.C, R17.1, R21.1, R22.1, R23.1, R24.1, S2.1, S2.2, U2.2, U4.1, U6.GND@1, U6.GND@22, U6.GND@38, U6.GND@39, U6.GND@47, U6.GND@59
GND2: BT3.2, C39.1, C40.-, C41.2, C42.-, C44.2, C45.2, C46.-, C47.-, C48.2, C49.2, C50.2, C52.2, C53.2, C54.1, C55.1, C56.2, C57.2, E3.3, E3.6, E3.7, E3.8, J13.GND, J14.1, J15.GND, J15.GND2, J16.3, J16.5, J16.9, JP39.4A, JP39.4B, JP40.2A, JP40.2B, JP40.3A, JP40.3B, JP45.GND, JP48.1, LED5.C, LED6.C, R29.1, R33.1, R34.1, R35.1, R36.1, S3.1, S3.2, U7.2, U8.1, U9.GND@1, U9.GND@22, U9.GND@38, U9.GND@39, U9.GND@47, U9.GND@59
GND3: BT4.2, C58.1, C59.-, C60.2, C61.-, C63.2, C64.2, C65.-, C66.-, C67.2, C68.2, C69.2, C71.2, C72.2, C73.1, C74.1, C75.2, C76.2, E4.3, E4.6, E4.7, E4.8, J19.GND, J20.1, J21.GND, J21.GND2, J22.3, J22.5, J22.9, JP55.4A, JP55.4B, JP56.2A, JP56.2B, JP56.3A, JP56.3B, JP61.GND, JP64.1, LED7.C, LED8.C, R41.1, R45.1, R46.1, R47.1, R48.1, S4.1, S4.2, U10.2, U11.1, U12.GND@1, U12.GND@22, U12.GND@38, U12.GND@39, U12.GND@47, U12.GND@59
INSERT: J3.P$4, Q1.1, R4.1
INSERT1: J6.P$4, Q2.1, R13.1
INSERT2: J13.P$4, Q3.1, R28.1
INSERT3: J19.P$4, Q4.1, R40.1
unnamed: LED1.A, R1.2
unnamed: LED2.A, R2.1
unnamed: D4.C, D5.C, J1.2, JP15.1
unnamed: D2.A, R16.1
unnamed: C17.1, U5.4
unnamed: C11.2, U1.XO, Y1.P$2
unnamed: C13.2, U1.XI, Y1.P$1
unnamed: D3.A, R12.1
unnamed: JP2.3A, JP2.3B, JP16.2
unnamed: LED3.A, R10.1
unnamed: LED4.A, R6.2
unnamed: IC1.1, R17.2, R18.1
unnamed: D8.A, R20.1
unnamed: IC3.1, R14.2, R15.1
unnamed: D7.A, R19.1
unnamed: C30.1, U4.4
unnamed: D9.C, D10.C, J11.2, JP31.1
unnamed: C35.2, U6.XO, Y2.P$2
unnamed: C36.2, U6.XI, Y2.P$1
unnamed: JP23.3A, JP23.3B, JP32.2
unnamed: LED5.A, R26.1
unnamed: LED6.A, R25.2
unnamed: IC2.1, R29.2, R30.1
unnamed: D13.A, R32.1
unnamed: D12.A, R31.1
unnamed: C49.1, U8.4
unnamed: D14.C, D15.C, J17.2, JP47.1
unnamed: C54.2, U9.XO, Y3.P$2
unnamed: C55.2, U9.XI, Y3.P$1
unnamed: JP39.3A, JP39.3B, JP48.2
unnamed: LED7.A, R38.1
unnamed: LED8.A, R37.2
unnamed: IC4.1, R41.2, R42.1
unnamed: D18.A, R44.1
unnamed: D17.A, R43.1
unnamed: C68.1, U11.4
unnamed: D19.C, D20.C, J23.2, JP63.1
unnamed: C73.2, U12.XO, Y4.P$2
unnamed: C74.2, U12.XI, Y4.P$1
unnamed: JP55.3A, JP55.3B, JP64.2
PDMCLK: E1.4, U1.~D37
PDMCLK1: E2.4, U6.~D37
PDMCLK2: E3.4, U9.~D37
PDMCLK3: E4.4, U12.~D37
PDMDATA: E1.1, U1.D36
PDMDATA1: E2.1, U6.D36
PDMDATA2: E3.1, U9.D36
PDMDATA3: E4.1, U12.D36
PWRIN: D1.A, J3.VIN0
PWRIN1: D6.A, J6.VIN0
PWRIN2: D11.A, J13.VIN0
PWRIN3: D16.A, J19.VIN0
RXI-0: D3.C, J7.1, TP5.P$1, U1.RXI-0, U5.2
RXI-1: D7.C, J12.1, TP10.P$1, U4.2, U6.RXI-0
RXI-2: D12.C, J18.1, TP25.P$1, U8.2, U9.RXI-0
RXI-3: D17.C, J24.1, TP36.P$1, U11.2, U12.RXI-0
SHLD: J5.SHLD1, J5.SHLD2, J5.SHLD3, J5.SHLD4, J5.SHLD5, J5.SHLD6, J5.SHLD7, J5.SHLD8
SHLD1: J9.SHLD1, J9.SHLD2, J9.SHLD3, J9.SHLD4, J9.SHLD5, J9.SHLD6, J9.SHLD7, J9.SHLD8
SHLD2: J15.SHLD1, J15.SHLD2, J15.SHLD3, J15.SHLD4, J15.SHLD5, J15.SHLD6, J15.SHLD7, J15.SHLD8
SHLD3: J21.SHLD1, J21.SHLD2, J21.SHLD3, J21.SHLD4, J21.SHLD5, J21.SHLD6, J21.SHLD7, J21.SHLD8
SWDCK: J2.4, TP1.P$1, U1.SWDCK
SWDCK1: J10.4, TP4.P$1, U6.SWDCK
SWDCK2: J16.4, TP23.P$1, U9.SWDCK
SWDCK3: J22.4, TP34.P$1, U12.SWDCK
SWDIO: J2.2, TP2.P$1, U1.SWDIO
SWDIO1: J10.2, TP7.P$1, U6.SWDIO
SWDIO2: J16.2, TP24.P$1, U9.SWDIO
SWDIO3: J22.2, TP35.P$1, U12.SWDIO
TXO-0: D2.C, J7.2, TP6.P$1, U1.TXO-0, U5.3
TXO-1: D8.C, J12.2, TP15.P$1, U4.3, U6.TXO-0
TXO-2: D13.C, J18.2, TP26.P$1, U8.3, U9.TXO-0
TXO-3: D18.C, J24.2, TP37.P$1, U11.3, U12.TXO-0
USBVCC: C12.1, C15.+, F2.2, JP12.2, Q1.3
USBVCC1: C25.1, C26.+, F1.2, JP30.2, Q2.3
USBVCC2: C45.1, C46.+, F3.2, JP46.2, Q3.3
USBVCC3: C64.1, C65.+, F4.2, JP62.2, Q4.3
VDD: C2.2, C7.1, C9.1, C19.1, E1.2, E1.5, J1.1, J2.1, J4.2, JP10.5A, JP10.5B, JP10.7A, JP10.7B, JP15.2, R3.2, U1.VDD@36, U1.VDD@37
VDD1: C14.2, C33.1, C34.1, C38.1, E2.2, E2.5, J8.2, J10.1, J11.1, JP24.5A, JP24.5B, JP24.7A, JP24.7B, JP31.2, R11.2, U6.VDD@36, U6.VDD@37
VDD2: C39.2, C52.1, C53.1, C57.1, E3.2, E3.5, J14.2, J16.1, J17.1, JP40.5A, JP40.5B, JP40.7A, JP40.7B, JP47.2, R27.2, U9.VDD@36, U9.VDD@37
VDD3: C58.2, C71.1, C72.1, C76.1, E4.2, E4.5, J20.2, J22.1, J23.1, JP56.5A, JP56.5B, JP56.7A, JP56.7B, JP63.2, R39.2, U12.VDD@36, U12.VDD@37
VIN: C5.+, D1.C, IC3.3, JP10.1A, JP10.1B
VIN1: C22.+, D6.C, IC1.3, JP24.1A, JP24.1B
VIN2: C42.+, D11.C, IC2.3, JP40.1A, JP40.1B
VIN3: C61.+, D16.C, IC4.3, JP56.1A, JP56.1B
VUSB: C10.1, F2.1, J5.VBUS1, J5.VBUS2, JP12.1, JP14.VBUS
VUSB1: C24.1, F1.1, J9.VBUS1, J9.VBUS2, JP29.VBUS, JP30.1
VUSB2: C44.1, F3.1, J15.VBUS1, J15.VBUS2, JP45.VBUS, JP46.1
VUSB3: C63.1, F4.1, J21.VBUS1, J21.VBUS2, JP61.VBUS, JP62.1
V_BATT: BT1.1, D4.A
V_BATT1: BT2.1, D9.A
V_BATT2: BT3.1, D14.A
V_BATT3: BT4.1, D19.A
~D0/RXI-1: JP11.1A, JP11.1B, U1.~D25
~D0/RXI-2: JP27.1A, JP27.1B, U6.~D25
~D0/RXI-3: JP43.1A, JP43.1B, U9.~D25
~D0/RXI-4: JP59.1A, JP59.1B, U12.~D25
~D1: JP27.4A, JP27.4B, U6.~D4
~D1/TXO-1: JP11.2A, JP11.2B, U1.~D24
~D1/TXO-2: JP27.2A, JP27.2B, U6.~D24
~D1/TXO-3: JP43.2A, JP43.2B, U9.~D24
~D1/TXO-4: JP59.2A, JP59.2B, U12.~D24
~D2: JP27.5A, JP27.5B, U6.~D22
~D2/A1: JP27.3A, JP27.3B, U6.~AD35
~D2/A2: JP43.3A, JP43.3B, U9.~AD35
~D2/A3: JP59.3A, JP59.3B, U12.~AD35
~D2/A6: JP11.3A, JP11.3B, U1.~AD35
~D3: JP11.4A, JP11.4B, U1.~D4
~D4: JP11.5A, JP11.5B, U1.~D22
~D5: JP11.6A, JP11.6B, U1.~D23
~D6: JP11.7A, JP11.7B, U1.~D27
~D7: JP11.8A, JP11.8B, U1.~D28
~D8: JP27.6A, JP27.6B, U6.~D23
~D8/A1: JP23.10A, JP23.10B, U6.~AD32
~D8/A2: JP39.10A, JP39.10B, U9.~AD32
~D8/A3: JP55.10A, JP55.10B, U12.~AD32
~D8/A8: JP2.10A, JP2.10B, U1.~AD32
~D9: JP27.7A, JP27.7B, U6.~D27
~D9/A1: JP23.9A, JP23.9B, U6.~AD12
~D9/A2: JP39.9A, JP39.9B, U9.~AD12
~D9/A3: JP55.9A, JP55.9B, U12.~AD12
~D9/A9: JP2.9A, JP2.9B, U1.~AD12
~D10: JP27.8A, JP27.8B, U6.~D28
~D10/A1: JP23.8A, JP23.8B, U6.~AD13
~D10/A2: JP39.8A, JP39.8B, U9.~AD13
~D10/A3: JP55.8A, JP55.8B, U12.~AD13
~D10/A10: JP2.8A, JP2.8B, U1.~AD13
~D11: TP18.P$1, U6.~D42
~D11/MOSI: JP2.7A, JP2.7B, U1.D7
~D11/MOSI1: JP23.7A, JP23.7B, U6.D7
~D11/MOSI2: JP39.7A, JP39.7B, U9.D7
~D11/MOSI3: JP55.7A, JP55.7B, U12.D7
~D12: TP17.P$1, U6.~D43
~D12/MISO: JP2.6A, JP2.6B, U1.~D6
~D12/MISO1: JP23.6A, JP23.6B, U6.~D6
~D12/MISO2: JP39.6A, JP39.6B, U9.~D6
~D12/MISO3: JP55.6A, JP55.6B, U12.~D6
~D13: JP43.4A, JP43.4B, U9.~D4
~D13/SCK: JP2.5A, JP2.5B, R1.1, U1.~D5
~D13/SCK1: JP23.5A, JP23.5B, R6.1, U6.~D5
~D13/SCK2: JP39.5A, JP39.5B, R25.1, U9.~D5
~D13/SCK3: JP55.5A, JP55.5B, R37.1, U12.~D5
~D14: JP43.5A, JP43.5B, U9.~D22
~D15: JP43.6A, JP43.6B, U9.~D23
~D15/SCL: J4.4, JP2.1A, JP2.1B, U1.~D39
~D15/SCL1: J8.4, JP23.1A, JP23.1B, U6.~D39
~D15/SCL2: J14.4, JP39.1A, JP39.1B, U9.~D39
~D15/SCL3: J20.4, JP55.1A, JP55.1B, U12.~D39
~D16: JP43.7A, JP43.7B, U9.~D27
~D16/A0: JP13.1A, JP13.1B, U1.~AD29
~D16/A1: JP28.1A, JP28.1B, U6.~AD29
~D16/A2: JP44.1A, JP44.1B, U9.~AD29
~D16/A3: JP60.1A, JP60.1B, U12.~AD29
~D17: JP43.8A, JP43.8B, U9.~D28
~D17/A1: JP13.2A, JP13.2B, U1.~AD11
~D17/A2: JP28.2A, JP28.2B, U6.~AD11
~D17/A3: JP44.2A, JP44.2B, U9.~AD11
~D17/A4: JP60.2A, JP60.2B, U12.~AD11
~D18: TP29.P$1, U9.~D42
~D19: TP28.P$1, U9.~D43
~D19/A1: J10.6, JP28.4A, JP28.4B, U6.~AD33/SWO
~D19/A2: J16.6, JP44.4A, JP44.4B, U9.~AD33/SWO
~D19/A3: J2.6, JP13.4A, JP13.4B, U1.~AD33/SWO
~D19/A4: J22.6, JP60.4A, JP60.4B, U12.~AD33/SWO
~D20: JP59.4A, JP59.4B, U12.~D4
~D21: JP59.5A, JP59.5B, U12.~D22
~D21/A1: JP28.6A, JP28.6B, U6.~AD31
~D21/A2: JP44.6A, JP44.6B, U9.~AD31
~D21/A3: JP60.6A, JP60.6B, U12.~AD31
~D21/A5: JP13.6A, JP13.6B, U1.~AD31
~D22: JP59.6A, JP59.6B, U12.~D23
~D23: JP59.7A, JP59.7B, U12.~D27
~D24: JP59.8A, JP59.8B, U12.~D28
~D25: TP40.P$1, U12.~D42
~D26: TP39.P$1, U12.~D43
~D28: TP9.P$1, U1.~D42
~D29: TP8.P$1, U1.~D43

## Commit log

2019-04-04 Fix I2C silk. Breakout UART0.
    [BlackBoard-Artemis.brd, BlackBoard-Artemis.sch]
2019-04-15 Rev FP for mics. Add decoupling to mics.
    [BlackBoard-Artemis.brd, BlackBoard-Artemis.sch]
2019-04-16 Update power jack. Change to PDM mics.
    [BlackBoard-Artemis.brd, BlackBoard-Artemis.sch]
2019-04-16 DRC resolved
    [BlackBoard-Artemis.brd]
2019-04-17 Change 10nF to 0.1uF on auto reset circuit
    [BlackBoard-Artemis.brd, BlackBoard-Artemis.sch]
2019-04-17 Change 10nF to 0.1uF on auto-reset circuit
    [BlackBoard-Artemis.brd, BlackBoard-Artemis.sch]
2019-05-10 Version x02 - now uses Artemis v10. One mic, more GPIO, better silk,
    [BlackBoard-Artemis-Panel.brd, BlackBoard-Artemis.brd, BlackBoard-Artemis.sch]
2019-05-10 Update silk on Artemis FP
    [BlackBoard-Artemis-Panel.brd, BlackBoard-Artemis.brd, BlackBoard-Artemis.sch]
2019-05-17 Adding production panel
    [BlackBoard-Artemis-Panel.GBL, BlackBoard-Artemis-Panel.GBO, BlackBoard-Artemis-Panel.GBS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]
2019-05-20 Fixing PWM on pin 7
    [BlackBoard-Artemis.brd, BlackBoard-Artemis.sch]
2019-05-22 Fix pin 33 silk indicator error
    [BlackBoard-Artemis.brd, BlackBoard-Artemis.sch]
2019-05-28 Change labels to match variant.
    [BlackBoard-Artemis.brd, BlackBoard-Artemis.sch]
2019-05-28 Bump version
    [BlackBoard-Artemis.brd]
2019-06-20 Adding ignore. Adding production panel.
    [BlackBoard-Artemis-Panel.GBL, BlackBoard-Artemis-Panel.GBO, BlackBoard-Artemis-Panel.GBS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]
2019-07-02 Move testpoint on BlackBoard
    [BlackBoard-Artemis.brd]

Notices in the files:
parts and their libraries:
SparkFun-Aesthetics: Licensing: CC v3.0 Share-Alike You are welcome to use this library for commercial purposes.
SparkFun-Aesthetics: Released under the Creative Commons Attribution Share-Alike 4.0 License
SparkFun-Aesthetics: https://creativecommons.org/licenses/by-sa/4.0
